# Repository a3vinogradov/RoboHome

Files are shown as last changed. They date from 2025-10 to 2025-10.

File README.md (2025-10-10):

# RoboHome

**Децентрализованная экосистема умного дома**

> *Умный дом, который не тупеет без интернета*

## О проекте

Автономная система, где каждое устройство работает независимо, но может объединяться в единое пространство через протокол RoboHomeLinq.

## 📁 Документация

- [Концепция](Docs/concept.md) - философия и архитектура
- [План разработки](Docs/roadmap.md) - текущий прогресс 
- [История изменений](Docs/concept_changelog.md) - эволюция проекта

## 📜 Лицензия

MIT License

**Автор:** a3v

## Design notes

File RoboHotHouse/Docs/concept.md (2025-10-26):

# **Концепт-документ: RoboHotHouse – Автономная система умной теплицы**

**Версия:** 0.1 

---

## **1. Видение продукта**
**RoboHotHouse** – автономная система для подогрева воздуха в теплице, обеспечивающая безопасную зимовку комнатных растений на балконе.

> *Ключевой принцип: «Не дать цветку замерзнуть!»*

---

## **2. Ключевые характеристики**

| Параметр | Значение/Примечание |
| --- | --- |
| **Измеряемые величины** | Температура, влажность (ANT20), давление (BMP280), освещенность (опционально) |
| **Порог обогрева** | +12°C (активация подогрева) |
| **Связь** | Wi-Fi 2.4 ГГц (внешняя антенна - опционально) |
| **Дисплей** | TFT 1.28" GC9A01 (240x240) |
| **Управление** | Тактовая кнопка (переключение экранов/сброс настроек) |
| **Питание** | ~220В → 5V/3.3V для электроники + 12V для обогревателя |

---

## **3. Аппаратная часть**

### **3.1. Основные компоненты**
- **Микроконтроллер:** ESP32
- **Датчики:** ANT20 (I2C), BMP280 (I2C), LDR (A0 - опционально)
- **Дисплей:** 1.28" TFT GC9A01 (SPI)
- **Управление:** Тактовая кнопка (GPIO16)
- **Обогреватель:** Коврик 5W или резисторы 10W

### **3.2. Безопасность**
- **Механический выключатель** на корпусе
- **Автомат 2А + УЗО** в цепи 220В
- **Закрытый корпус** перед подключением к сети

---

## **4. Программное обеспечение**

### **4.1. Основные функции**
- Непрерывный мониторинг датчиков (30 сек интервал)
- Автоматический обогрев при T < +12°C
- Кольцевой буфер данных (24+ часов истории)
- REST API (`/status` - текущее состояние)
- Интеграция с RoboHome

### **4.2. Логика управления**
- Включение подогрева при снижении температуры ниже 12*С
- Выключение подогрева при повышении температуры до 14*С

### **5. Особенности конструкции**
**Колпак:** Обрезанная бутылка 5л. 
**Корпус:** Основание PLA, крепления PETG
**Антенна:** Возможность подключения внешней для улучшения сигнала

**Лицензия:** MIT
**Автор:** a3v1
**Репозиторий:** gitverse.ru/a3v1/RoboHome

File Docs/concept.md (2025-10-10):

# **Концепт-документ: RoboHome – Автономная экосистема умного дома**  
**Версия:** 0.2  

---

## **1. Видение проекта**  
**RoboHome** – это децентрализованная система умного дома, где каждое устройство автономно, но способно интегрироваться в единую экосистему. 
Ключевая философия:  
> *«Умный дом должен оставаться умным даже без интернета и центрального сервера»*.

---

## **2. Ключевые принципы**  

| Принцип | Реализация в RoboHome |
|---|---|
| **Автономность** | Устройства выполняют основные функции без связи с сервером (например, полив по алгоритму). |
| **Децентрализация** | Нет единой точки отказа. RoboCore выполняет только координационные функции |
| **Локальность** | Приоритет JSON/HTTP в локальной сети. Облако – опционально. |
| **Безопасность** | Многоуровневая валидация всех команд и операций |
| **Масштабируемость**  | Модульная архитектура для легкого добавления новых устройств |

---

## **3. Компоненты системы**  

### **3.1. RoboCore**  
**Роль:** Координатор системы.  
**Функции:**  
- Сбор и агрегация данных от устройств
- Визуализация через веб-интерфейс
- Отправка макрокоманд устройствам 

**Технологии:**  
- ToDo: заполнить  

---

### **3.2. RoboClime**
**Роль:** Комнатная метеостанция  
**Функции:**  
- Замер температуры, влажности, давления, освещенности.  
- Кеширование данных при потере связи.  
- Логирование всех операций

**Железо:**  
- Микроконтроллер: ESP8266-07
- Датчики: CNT-20, BMP-280, LDR

---

### **3.3. RoboHotHouse**
**Роль:** Теплица для зимовки комнатных растений  
**Функции:**  
- Замер температуры, влажности, давления, освещенности.  
- Подогрев при температурах ниже +12.
- Кеширование данных при потере связи.  
- Логирование всех операций

**Железо:**  
- Микроконтроллер: ESP8266-07
- Датчики: CNT-20, BMP-280, LDR
- Нагреватель: Теплый коврик

---

### **3.4. RoboPlant**  
**Роль:** Интеллектуальная система полива.  
**Функции:**  
- Автоматический полив по показаниям датчиков
- REST API для управления
- Контроль уровня воды и обнаружение протечек
- Логирование всех операций

**Железо:**  
- Микроконтроллер: ESP8266-07
- Датчики: влажности почвы, уровня воды
- Исполнительные устройства: насос

---

### **3.5. RoboWind**  
**Роль:** Уличная метеостанция
**Функции:**  
- Замер температуры, влажности, давления.  
- Синхронизация с «Народным мониторингом».  
- Кеширование данных при потере связи.  

**Железо:**  
- ESP8266 + датчики.  

---

## **4. Взаимодействие устройств**  
```mermaid
flowchart LR
    B[RoboCore] ->> |Запрос данных по дате (HTTP)| A[RoboWind]
    A[RoboWind] ->> |Отправка метеоданных за период| B[RoboCore]
    B ->>|Запрос истории состояний по дате (HTTP)| C[RoboPlant]
    C -->|JSON: plant/status| B
```

---

## **5. Техническая реализация**  

### **5.1. Протоколы**  
- **JSON** – основной канал связи (топики: `robohome/[device]/[data]`).  
- **HTTP REST** – для управления (например, ручной запуск полива).  
- **Резервный канал** – Telegram-бот через SIM-модуль (опционально).  

---

## **6. Лицензия и контакты**  
- **Лицензия:** MIT – свободное использование и модификация.  
- **Автор:** a3v  

---

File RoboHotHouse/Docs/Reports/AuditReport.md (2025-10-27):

**Отчет по аудиту компонентов управления нагрузкой ~220В**  
**Проект:** RoboHotHouse  
**Дата проведения аудита:** текущая  
**Цель:** Оценка пригодности имеющихся компонентов для коммутации нагрузки ~220В в системе обогрева.  

---

### **1. Реле механические**  
#### **Наименования:**  
1. **SONGLE SRD-05VDC-SL-C**  
   - **Напряжение катушки:** 5 В  
   - **Коммутируемое напряжение:** ~250 В  
   - **Максимальный ток:** 10 А  
   - **Примечание:** Требуется пропайка разъемов.  

2. **TONGLING JQC-3FF-S-Z**  
   - **Напряжение катушки:** 5 В  
   - **Коммутируемое напряжение:** ~250 В  
   - **Максимальный ток:** 10 А  
   - **Примечание:** Готов к использованию.  

#### **Вывод по механическим реле:**  
- Оба реле подходят для управления нагрузкой ~220В.  
- Ток коммутации (10 А) значительно превышает требуемый для обогревательного коврика (5 Вт ≈ 0.023 А).  
- **Риски:** Наличие механических контактов, возможное искрение при коммутации индуктивной нагрузки.  

---

### **2. Реле твердотельные**  
#### **Наименования:**  
1. **G3MB-202P**  
   - **Напряжение управления:** 5 В  
   - **Коммутируемое напряжение:** 240 В (переменный ток)  
   - **Максимальный ток:** 2 А  
   - **Примечание:** Бесшумная работа, отсутствие механического износа.  

#### **Вывод по твердотельным реле:**  
- Реле **G3MB-202P** полностью удовлетворяет требованиям проекта.  
- Ток коммутации (2 А) избыточен для нагрузки (0.023–0.045 А).  
- **Преимущества:** Отсутствие дребезга контактов, долговечность, совместимость с цифровыми сигналами ESP32.  

---

### **3. Сравнительный анализ**  
| Параметр | Механическое реле | Твердотельное реле |  
|---|---|---|
| **Ток коммутации** | 10 А | 2 А |  
| **Напряжение изоляции** | ~250 В | ~240 В |  
| **Долговечность** | ~100 000 циклов | ~10 000 000 циклов  |  
| **Уровень шума** | Щелчки при работе | Бесшумная работа |  
| **Подключение** | Требует пропайки  | Готово к использованию |  

---

### **4. Рекомендации**  
1. **Твердотельное реле G3MB-202P** является предпочтительным вариантом для проекта благодаря:  
   - Высокой надежности и долговечности.  
   - Бесшумной работе.  
   - Простоте интеграции с ESP32.  
2. **Механические реле** могут быть использованы как резервный вариант, но требуют дополнительной обвязки (например, защитного диода для катушки).  

---

**Заключение:**  
Компоненты, имеющиеся в наличии, полностью пригодны для управления нагрузкой ~220В в рамках проекта RoboHotHouse. Наибольшую эффективность и безопасность обеспечит использование твердотельного реле **G3MB-202P**.  

*Документ подготовлен в рамках Этапа 1 (НИОКР) проекта RoboHotHouse.*

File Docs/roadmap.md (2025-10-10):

## **RoboHome Development Roadmap**  
**Без жесткой привязки к срокам**  
*"Поэтапная разработка с фокусом на архитектуре и интеграции"*  

### 🎯 RoboHome: Единая карта готовности

| Компонент | Концепция | Функциональность | Сетевое подключение | Конфигурируемость | Протокол RoboHomeLinq |
|---|---|---|---|---|---|
| **RoboCore** | ✅ | 🟡 | ✅ | ❌ | ❌ |
| **RoboPlant#1** | ✅ | ✅ | ✅ | ✅ | ❌ |
| **RoboPlant#2** | ✅ | ✅ | ✅ | ✅ | ❌ |
| **RoboWind** | ✅ | ✅ | ✅ | ✅ | ❌ |
| **RoboClime** | ✅ | ✅ | ❌ | ❌ | ❌ |
| **RoboHotHouse** | 🟡 | ❌ | ❌ | ❌ | ❌ |

---

### **Детализация критериев по компонентам**

#### **RoboCore**
- **Концепция**: ✅
  - [x] Проект инициализирован
  - [x] Concept-документ готов
- **Функциональность**: 🟡
  - [~] Веб-интерфейс для мониторинга
  - [x] База данных для хранения показаний
  - **Эмуляторы устройств для тестирования:**
    - [~] Эмулятор RoboBase (абстрактное тестовое устройство)
    - [ ] Эмулятор RoboPlant
    - [ ] Эмулятор RoboWind
    - [ ] Эмулятор RoboClime
    - [ ] Эмулятор RoboHotHouse
- **Сетевое подключение**: ✅
  - [x] Доступен в локальной сети
- **Конфигурируемость**: ❌
  - [ ] Базовая настройка интерфейса
  - [ ] Регистрация нового устройства
- **Протокол RoboHomeLinq**: ❌
  - [ ] Запрос текущего состояния
  - [ ] Запрос истории 
  - [ ] Отправка макрокоманд

#### **RoboClime**
- **Концепция**: ✅
  - [x] Проект инициализирован
  - [x] Concept-документ готов
- **Функциональность**: ✅
  - [x] Замер температуры, влажности, давления, освещенности
  - [x] Органы управления
  - [x] Логирование данных
- **Сетевое подключение**: ❌
  - [ ] Wi-Fi подключение
  - [ ] Локальный HTTP сервер
- **Конфигурируемость**: ❌
  - [ ] Админка в веб-интерфейсе
- **Протокол RoboHomeLinq**: ❌
  - [ ] Предоставление текущего состояния
  - [ ] Предоставление истории показаний
  - [ ] Прием макрокоманд 

#### **RoboHotHouse**
- **Концепция**: 🟡
  - [~] Проект инициализирован
  - [ ] Concept-документ готов
- **Функциональность**: ❌
  - [ ] Замер температуры, влажности, освещенности
  - [ ] Автоматический подогрев при +12°C
  - [ ] Логирование операций и показаний
- **Сетевое подключение**: ❌
  - [ ] Wi-Fi подключение
  - [ ] Локальный HTTP сервер
- **Конфигурируемость**: ❌
  - [ ] Админка в веб-интерфейсе
- **Протокол RoboHomeLinq**: ❌
  - [ ] Предоставление текущего состояния
  - [ ] Предоставление истории показаний
  - [ ] Прием макрокоманд 

#### **RoboPlant**
- **Концепция**: ✅
  - [x] Проект инициализирован
  - [x] Concept-документ готов
- **Функциональность**: ✅
  - [x] Автоматический полив по датчикам влажности почвы
  - [x] Контроль уровня воды в резервуаре
  - [x] Обнаружение протечек
  - [x] Логирование операций
  - [x] Web-интерфейс
- **Сетевое подключение**: ✅
  - [x] Wi-Fi подключение
  - [x] Локальный HTTP сервер
- **Конфигурируемость**: ✅
  - [x] Админка в веб-интерфейсе
- **Протокол RoboHomeLinq**: ❌
  - [ ] Предоставление текущего состояния
  - [ ] Предоставление истории показаний
  - [ ] Прием макрокоманд 

#### **RoboWind**
- **Концепция**: ✅
  - [x] Проект инициализирован
  - [x] Concept-документ готов
- **Функциональность**: ✅
  - [x] Замер температуры, влажности, давления
  - [x] Отправка данных в narodmon.ru
  - [x] Web-интерфейс
- **Сетевое подключение**: ✅
  - [x] Wi-Fi подключение
  - [x] Локальный HTTP сервер
- **Конфигурируемость**: ✅
  - [x] Админка в веб-интерфейсе
- **Протокол RoboHomeLinq**: ❌
  - [ ] Предоставление текущего состояния
  - [ ] Предоставление истории показаний
  - [ ] Прием макрокоманд 

---

### **Ключевые вехи системы**

**Ближайшие цели:**
- [ ] RoboHotHouse: Концепт и реализация устройства
- [ ] RoboCore: Концепт протокола RoboHomeLinq
- [ ] RoboClime: Реализация сетевого подключения

**Целевое состояние:**
- [ ] Все устройства поддерживают протокол RoboHomeLinq
- [ ] RoboCore полностью управляет экосистемой

**Легенда:**
- ✅ - Выполнено
- 🟡 - В процессе
- ❌ - Не готово
- [x] - Задача выполнена
- [~] - Задача в процессе
- [ ] - Задача не начата

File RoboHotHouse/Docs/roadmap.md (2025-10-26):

# **RoadMap проекта RoboHotHouse**
**Версия:** 0.1

---

## **Этап 1. НИОКР**
**Срок:** 28-10-2025 - 11-11-2025
**Цель:** Снижение степени новизны проекта и связанных с этим рисков.

**Задачи:**
1. Исследование способов управления переменной нагрузкой
2. Тестирование доступных способов управления переменной нагрузкой
   - Реле механическое
   - Реле твердотельное
3. Аудит компонентов управления нагрузкой ~220В из наличия
4. Исследование нагревательных возможностей коврика
5. Исследование нагревательных возможностей металло-керамических резисторов
6. Прошивка ESP32 в среде VSCode + PIO
7. Подключение датчиков и дисплея к ESP32
8. Схема управления ~220В с раздельным питанием и гальванической развязкой
9. УЗО
   - Принцип действия, характеристики
   - Выбор УЗО
   - Покупка УЗО
   - Установка УЗО

**Результат:**
- [ ] Отчет по способам управления нагрузкой ~220В
- [ ] Лабораторная работа по управлению нагрузкой ~220В и отчет по ней
- [ ] Отчет по аудиту компонентов управления нагрузкой ~220В
- [ ] Лабораторная работа по исследованию нагревательных возможностей коврика и резисторов. Отчет
- Лабораторные работы по подключению модулей к ESP32
  - [ ] Блинкер
  - [ ] AHT20
  - [ ] BMP280
  - [ ] Дисплей
- [ ] Схема управления нагрузкой ~220В с помощью контроллера
- [ ] Лабораторная работа по управлению нагрузкой ~220В с помощью контроллера
- [ ] Выбор УЗО и автомата. Расчет. Отчет
- [v] Установка защиты (УЗО и автомат) на балконе

##**Этап 2. Высоковольтная часть**
**Срок:** Дни [уточнить по результатам Этапа 1] 
**Цель:** 
- Сделать розетку 220В, которая управлялась бы сигналом 3.3В. 
- Сделать DC-DC преобразователь для обеспечения питания esp32

**Задачи:**
1. Схема электрическая 
2. Определение управляющего интерфейса (с гальванической развязкой)
3. Разводка PCB
4. Плата (ЛУТ)
5. Пайка компонентов 
6. Компоновка
7. 3d модель корпуса
8. Печать корпуса
9. Сборка узла высоковольтной части

**Результат:** 

[ ] Закрытая коробка с
- проводом и вилкой ~220В
- розеткой для включения коврика (не хочу на этом этапе резать провода)
- разъемом JST-npin для выдачи стабилизированных 5В для контроллера и линий управления выключателями (Релейный модуль G3MB-202P предположительно) 

##**Этап 3. Прототип**

**Срок:** *уточнить по результатам Этапа 2*

**Цель:** 
- создание полнофункционального стенда на макетке.

**Задачи:**
1. Сборка стенда на макетке (esp32, aht-20, bmp-280, tft 1.28)
2. Прошивка, реализующая
    - логику управления нагрузкой
    - вывод показателей на дисплей
    - управление дисплеем кнопкой
3. Выходные каскады управления нагрузкой с транзисторами и оптопарами.
4. Подключение к высоковольтному узлу и реальное управление нагрузкой. 
5. Выбор, реализация и настройка алгоритма поддержания заданной температуры. 
6. Проверка на утечку тока и перегрев высоковольтной части.

**Результат:**

- [ ] Стенд на макетке: esp32 и управление нагрузкой по наперед заданному алгоритму
- [ ] Отчет: Проверка на утечку тока и перегрев высоковольтной части.

##**Этап 4. Изделие**

**Срок:**  *уточнить по результатам Этапа 3*

**Цель:** 
- Создать работающее устройство 

**Задачи:**
1. Схема электрическая 
2. Разводка PCB
3. Изготовление платы (ЛУТ)
4. Пайка компонентов (контроллер съемный)
3. Модель корпуса
4. Печать корпуса
5. Сборка изделия
6. Отладка и настройка

**Результат:** 
- [ ] Управление нагрузкой по наперед заданному алгоритму
- [ ] Эстетичное, безопасное устройство.

##**Этап 5. Поддержка RoboHomeLinq**

**Срок:** Не определен. 

**Цель:** 
- Добавление к устройству веб интерфейса и поддержки протокола RoboHomeLinq

**Задачи:**
1. Веб-интерфейс
   - стартовая страница с текущими показаниями
   - настройки 
   - about
2. Страница лога и сам лог
3. Интеграция в RoboHome
   - поддержка протокола RoboHomeLinq
   - добавление адаптеров для RoboHotHouse в RoboCore

**Результат:** 
- RoboHotHouse отображается в интерфейсе RoboCore
- RoboHotHouse выполняет команды, поступившие из интерфейса RoboCore

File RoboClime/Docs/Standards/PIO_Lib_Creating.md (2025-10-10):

# Руководство по созданию библиотек в PlatformIO

## 🎯 **Основные принципы**

### 1. **Структура библиотеки**
```
MyLibrary/
├── library.json          # Обязательно!
├── MyLibrary.h           # Главный заголовок
├── src/                  # Исходные файлы
│   ├── Class1.h
│   ├── Class2.cpp
│   └── ...
└── examples/             # Примеры использования
    └── BasicExample/
        └── BasicExample.ino
```

### 2. **Критически важные моменты**
- **library.json** - должен быть в корне библиотеки
- **MyLibrary.h** - главный заголовок должен быть в корне
- **Платформа** - указывайте поддерживаемые платформы

## 📝 **Пошаговое создание библиотеки**

### Шаг 1: Создаем структуру папок
```bash
# В папке lib/ вашего проекта
mkdir MyLibrary
cd MyLibrary
mkdir src examples
```

### Шаг 2: Создаем library.json
```json
{
    "name": "MyLibrary",
    "version": "1.0.0",
    "description": "Описание вашей библиотеки",
    "keywords": "keyword1, keyword2",
    "authors": [
        {
            "name": "Ваше имя",
            "email": "email@example.com"
        }
    ],
    "frameworks": "arduino",
    "platforms": "espressif8266, espressif32",
    "build": {
        "includeDir": ".",
        "srcDir": "src"
    }
}
```

**Ключевые параметры:**
- `"includeDir": "."` - указывает, где искать заголовочные файлы
- `"srcDir": "src"` - указывает, где исходные файлы

### Шаг 3: Создаем главный заголовок (MyLibrary.h)
```cpp
#pragma once

// Главный заголовок библиотеки
#include "src/MyClass.h"
#include "src/MyConfig.h"

namespace MyLibrary {
    // Объявления или using-директивы
}
```

### Шаг 4: Создаем исходные файлы в src/
**src/MyClass.h:**
```cpp
#pragma once
#include <Arduino.h>

namespace MyLibrary {
    class MyClass {
    public:
        void begin();
        void update();
    private:
        // поля класса
    };
}
```

**src/MyClass.cpp:**
```cpp
#include "MyClass.h"

namespace MyLibrary {
    void MyClass::begin() {
        // инициализация
    }
    
    void MyClass::update() {
        // основная логика
    }
}
```

### Шаг 5: Создаем пример использования
**examples/BasicExample/BasicExample.ino:**
```cpp
#include <MyLibrary.h>

MyLibrary::MyClass myObject;

void setup() {
    Serial.begin(115200);
    myObject.begin();
}

void loop() {
    myObject.update();
    delay(100);
}
```

## ⚙️ **Конфигурация platformio.ini**
```ini
[env:nodemcuv2]
platform = espressif8266
board = nodemcuv2
framework = arduino

; Библиотека автоматически подхватится из lib/
; Явное указание не требуется, но можно добавить:
lib_deps = 
    MyLibrary
```

## 🔧 **Работа с зависимостями**

### Зависимость от другой библиотеки
**library.json:**
```json
{
    "name": "MyLibrary",
    "version": "1.0.0",
    "dependencies": {
        "SomeOtherLibrary": "*"
    },
    "build": {
        "includeDir": ".",
        "srcDir": "src"
    }
}
```

### Вложенные зависимости
Если ваша библиотека зависит от другой вашей же библиотеки:
```json
{
    "dependencies": {
        "EventLib": "*",
        "ButtonLib": "*"
    }
}
```

## 🐛 **Диагностика проблем**

### 1. Библиотека не находится
**Симптом:** `fatal error: MyLibrary.h: No such file or directory`

**Решение:**
- Проверьте наличие `library.json`
- Убедитесь, что `MyLibrary.h` в корне библиотеки
- Добавьте в `platformio.ini`:
  ```ini
  lib_extra_dirs = lib/MyLibrary
  build_flags = -Ilib/MyLibrary
  ```

### 2. Файлы внутри библиотеки не находятся
**Симптом:** Ошибки компиляции файлов внутри src/

**Решение:**
- В `MyLibrary.h` используйте правильные пути:
  ```cpp
  #include "src/MyClass.h"    // если файлы в src/
  #include "MyClass.h"        // если файлы в корне
  ```

### 3. Проверка видимости библиотеки
```bash
# Убедитесь, что PlatformIO видит библиотеку
pio lib list

# Принудительно обновить кэш библиотек
pio pkg update
```

## 🚀 **Продвинутые настройки**

### Многофайловая библиотека
```
MyLibrary/
├── library.json
├── MyLibrary.h
├── src/
│   ├── Core/
│   │   ├── Core.h
│   │   └── Core.cpp
│   ├── Network/
│   │   ├── Network.h
│   │   └── Network.cpp
│   └── Sensors/
│       ├── Sensor.h
│       └── Sensor.cpp
└── examples/
    ├── BasicExample/
    └── AdvancedExample/
```

**MyLibrary.h:**
```cpp
#pragma once

// Подключаем все компоненты
#include "src/Core/Core.h"
#include "src/Network/Network.h"
#include "src/Sensors/Sensor.h"

namespace MyLibrary {
    // Объединяем все пространства имен
    using namespace Core;
    using namespace Network;
    using namespace Sensors;
}
```

## 💡 **Лучшие практики**

1. **Именование** - используйте осмысленные имена, избегайте пробелов
2. **Версионирование** - следуйте семантическому версионированию (1.0.0, 1.0.1, etc.)
3. **Документация** - добавляйте комментарии и примеры
4. **Тестирование** - создавайте примеры в папке examples/
5. **Совместимость** - явно указывайте поддерживаемые платформы

## 📋 **Чеклист создания библиотеки**

- [ ] Создана папка библиотеки в `lib/`
- [ ] Добавлен `library.json` с правильными путями
- [ ] Создан главный заголовок `MyLibrary.h`
- [ ] Исходные файлы размещены в `src/`
- [ ] Добавлены примеры в `examples/`
- [ ] Протестирована компиляция
- [ ] Указаны зависимости (если есть)

Теперь вы можете создавать хорошо структурированные библиотеки в PlatformIO! 🎉

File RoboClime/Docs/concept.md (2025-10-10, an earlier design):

# **Концепт-документ: RoboClime – Автономный модуль мониторинга микроклимата**

**Версия:** 0.3 

---

## **1. Видение продукта**

**RoboClime** – это компактный модуль для точного мониторинга параметров атмосферы (температура, влажность, давление). Устройство является частью экосистемы RoboHome и фокусируется на надежности данных за счет аппаратной изоляции датчиков.

> *Ключевой принцип: «Точные данные здесь и сейчас. Стабильность важнее функций».*

---

## **2. Ключевые характеристики**

| Параметр | Значение/Примечание |
| --- | --- |
| **Измеряемые величины** | Температура, относительная влажность (ANT20), атмосферное давление (BMP280), **освещенность (опционально)**|
| **Связь** | Wi-Fi 2.4 ГГц (внешняя штыревая антенна - **опционально**) |
| **Интерфейсы** | USB Type-C (питание 5V) |
| **Управление** | Тактовая кнопка (основной орган) с возможностью параллельного подключения вибродатчика (опционально, для тестирования в реальных условиях). |
| **Плата** | Односторонняя (ЛУТ) |
| **Корпус** | 3D-печать, **двойные стенки с воздушным зазором** для термоизоляции датчиков |
| **Обновление прошивки**| Внутренний разъем для программатора |

---

## **3. Аппаратная часть**

### **3.1. Ядро системы**
*   **Микроконтроллер:** ESP8266-07 flash 1М
*   **Датчики:**
    *   ANT20 (Temperature & Humidity, I2C)
    *   BMP280 (Barometric Pressure, I2C)
	*   Датчик освещенности (опционально, аналоговый вход A0)
*   **Дисплей** 1.28" TFT GC9A01 (240x240)
*   **Орган управления:** Тактовая кнопка (GPIO16). На плате реализована возможность параллельного подключения вибродатчика для полевых испытаний.
*   **Антенная система:** Возможность подключения внешней антенны (опционально)
*   **Резерв:** Выведенная контактная площадка (GPIO12) для будущих расширений (управление подсветкой, тач-скрин и т.д.)

### **3.2. Конструктивные особенности**
*   **Термоизоляция:** Датчики вынесены в изолированный отсек с двойными стенками
*   **Вентиляция:** Отверстия для вентиляции только в зоне датчиков
*   **Доступ:** Лючок для доступа к разъему программатора

---

## **4. Программное обеспечение**

### **4.1. Прошивка**
*   **Режим работы:** Постоянное питание от USB
*   **Управление дисплеем:** Постоянная работа. Яркость фиксированная (аппаратная).
*   **Взаимодействие:** REST API для предоставления данных (`/status`)

### **4.2. Логика работы**
1. Непрерывный опрос датчиков 
2. Хранение истории показаний в кольцевом буфере
3. Предоставление данных по API

---

## **5. Особенности реализации**
*   **Стратегия внедрения:** Функциональность устройства в ограниченном объеме реализуется и тестируется на макетной плате (Стенд 1, NodeMCU) до этапа изготовления конечного изделия. Это гарантирует готовность системы к мониторингу к началу ночных заморозков, даже если сроки изготовления корпуса и платы будут сдвинуты.
*   **Орган управления:** Тактовая кнопка подключена на GPIO16. Возможность подключения вибродатчика реализована аппаратно для тестирования.
*   **Термоизоляция:** Физическое отделение датчиков от источников тепла
*   **Разъем программатора:** 5-пиновый (GPIO0, RST, TX, RX, GND) для легкого обновления

---

**Лицензия:** MIT  
**Автор:** a3v1  
**Репозиторий:** gitverse.ru/a3v1/RoboHome  

---

**Утверждено к реализации.**  
Начало работ: 25-08-2025  
Плановый срок завершения: 42 дня

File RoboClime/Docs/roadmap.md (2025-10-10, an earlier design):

# **Дорожная карта (Roadmap) проекта RoboClime**
**Версия:** 0.4
**Общий срок:** 46 дней

---

### **Этап 1: НИОКР (Исследования и подготовка)**
**Срок:** Дни 1-7 (28.08 - 03.09)
**Цель:** Подготовить все компоненты и решения для быстрой сборки прототипа.

| Задача | Результат | Статус |
| --- | --- | ---|
| **1.1. Конструктив разъема программатора**  | Выбран тип разъема (скорее всего, 6-пиновый SH1.0). Спроектирована отладочная плата с кнопками FLASH и RST. | ✅ Выполнено с изменениями|
| **1.2. Изготовление шлейфа программатора**  | Готовый шлейф с ключом/полярностью, исключающей неправильное подключение к целевому устройству. | ✅ Выполнено без ключа|
| **1.3. Тест вибродатчика (SW-18020P)** | Подтверждена чувствительность на падение с высоты 1-2 см. Подобран резистор для нужной чувствительности. | ✅ Выполнено | 
| **1.4. Тест дисплея 1.28 TFT** | Вывод пикселя, символа, примитива, картинки | ✅ Выполнено |

*Сроки сдвинуты на 2 дня.*

---

### **Этап 2: Прототип на макетке**
**Срок:** Дни 10-21 (04.09 - 16.09)
**Цель:** Собрать и проверить работоспособность всей схемы и логики.

| Задача  | Результат  | Статус |  
| --- | --- | --- |
| **2.1. Сборка на макетке** | ESP8266, дисплей, датчики (ANT20+BMP280).  | ✅ Выполнено |
| **2.2. Базовая прошивка (Foundation)** | Прошивка, которая выводит данные с всех датчиков в Serial Monitor. Проверка работы I2C.  |✅ Выполнено |
| **2.3. Прошивка**  | Вывод на экран текущей температуры, температурных экстремумов за последние сутки |✅ Выполнено |
| **2.4. Прошивка (Сеть и WEB)** | Поднят простейший WEB-сервер. Страница `192.168.x.x/status` возвращает JSON с данными датчиков.  | Отложено на 4 этап |

---
### **Этап 2.5: Внеочередной НИОКР**
**Срок:** Дни 22-24 (17.09 - 18.09)
**Цель:** Аудит GPIO в проекте с целью подтвердить возможность подключения тактовой кнопки и/или вибродатчика.
| Задача  | Результат  | Статус |  
| --- | --- | --- |
| **2.5.1 Карта GPIO**| Составить список существующих GPIO. Составить список уже занятых GPIO. Определить количество свободных GPIO  | ✅ Выполнено |
| **2.5.2 Тест кнопки и вибродатчика**| Проверить возможность параллельного включения тактовой кнопки и вибродатчика. Подтвердить возможность использования такой схемы для сброса настроек wifi| ✅ Выполнено |
| **2.5.3 Тест датчика освещенности**| Проверить возможность использования датчика освещенности.| ✅ Выполнено |

### **Этап 3: Изделие (Корпус, плата, сборка)**
**Срок:** Дни 25-46 (19.09 - 10.10) 
**Цель:** Создать готовое к использованию устройство.
**Итог:** Устройство собрано, прошито и запущено в эксплуатацию. Расхождение температур со стендом #1 менее 0.3°C - в пределах допустимой погрешности.

| Задача  | Результат  | Статус | 
| --- | --- | --- |
| **3.1. Моделирование корпуса (Fusion 360)** | Готовая 3D-модель корпуса с двойными стенками, посадочными местами под плату и разъем программатора.  | ✅ Выполнено |
| **3.2. Печать и доводка корпуса** | Напечатанный и доведенный (подшлифованный) корпус. Проверка совместимости всех компонентов. | ✅ Выполнено |
| **3.3. Схема и разводка платы (ЛУТ)** | Готовая к переносу на текстолит односторонняя схема. Все компоненты помещаются в корпус. | ✅ Выполнено |
| **3.4. Изготовление и пайка платы** | Готовая паяная плата, установленная в корпус. | ✅ Выполнено |
| **3.5. Изготовление и пайка платы программатора** | Готовая паяная плата программатора | ✅ Выполнено |
| **3.6. Финальная прошивка ("Продакшн")** | **Готовое изделие.** Вывод на дисплей текущей температуры и суточных экстремумов. | ✅ Выполнено (Рефакторинг отложен на 4 этап) |

---
**Примечание:** Этап 3 успешно завершен 10.10.2025. Все работы по рефакторингу и улучшениям переносятся на Этапы 4 и 5. Сроки по этапам 4 и 5 будут уточнены отдельно.

---
### **Этап 4: Доработка прошивки (После 37 дней)**
*   **4.0. Техдолг: глубокий рефакторинг прошивки. Аудит компонентов.
*   **4.1. Страница Index** Вывод текущих показаний температуры и суточных экстремумов.
*   **4.2. Страница About** Вывод информации о проекте.
*   **4.3. Страница Settings** Настройки wifi, периода опроса, времени сброса экстремумов и т.п.
*   **4.4. Страница с логом показаний:** Вывод истории измерений за последние N часов.
*   **4.5. Реализация REST API:** Полноценное API для интеграции с RoboHome (отправка данных, управление).

---
### **Этап 5: Улучшения (После 37 дней)**
*   **5.1. Анимация на дисплее:** Плавные графики или визуализация данных прямо на дисплее.
*   **5.2. Диаграммы в WEB-интерфейсе:** Построение графиков температуры/давления прямо в браузере.
*   **5.3. Управление** Сенсор переключает страницы. Определить состав данных на страницах и логику переключения
*   **5.4. Реализация функционала датчика освещенности** периодический опрос датчика, сохранение истории, графики, совмещенные с температурой.

---

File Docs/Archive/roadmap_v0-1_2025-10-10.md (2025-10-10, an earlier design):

### **RoboHome Development Roadmap**  
**Без жесткой привязки к срокам**  
*"Поэтапная разработка с фокусом на архитектуре и интеграции"*  

---

### **🔹 Этап 1: Архитектура ядра (RoboCore)**  
**Цель:** Проектирование и базовая реализация центрального модуля управления.  

| Компонент | Задачи | Критерии завершения |
|---|---|---|
| **Ядро системы** | - Определение API-интерфейсов<br>- Реализация JSON-протокола | - Готовы спецификации API<br>- Рабочий HTTP-сервер |
| **База данных** | - Выбор СУБД (PostgreSQL)<br>- Схема хранения данных | - Сохранение/чтение тестовых данных |
| **UI** | - Веб-интерфейс (админ-панель + клиентская часть) | - Готова админка и фронтенд <br>- Интерфейс поддерживает основные сценарии управления |

---

### **🔹 Этап 2: Эмулятор метеостанции**  
**Цель:** Создание программного эмулятора RoboWind для тестирования.  

| Компонент | Задачи | Критерии завершения |
|---|---|---|
| **Эмулятор** | - Генерация тестовых данных (T/H/P)<br>- REST API для управления | - Имитация реального устройства |
| **Интеграция** | - Подключение к RoboCore<br>- Тестирование передачи данных | - Корректное отображение в веб-интерфейсе  |

---

### **🔹 Этап 3: Эмулятор автополивалки**  
**Цель:** Виртуальная модель RoboPlant для отладки логики.  

| Компонент | Задачи | Критерии завершения |
|---|---|---|
| **Эмулятор** | - Моделирование полива<br>- Имитация датчиков влажности | - Реализация всех API-эндпоинтов |
| **Интеграция** | - Тестирование с RoboCore<br>- Проверка реакций на команды | - Автоматический полив по данным от RoboCore |

---

### **🔹 Этап 4: Создание автополивалки (v3)**  
**Цель:** Разработка третьего экземпляра автополивалки.  

| Компонент | Задачи | Критерии завершения |
|---|---|---|
| **Аппаратная часть** | - Проектирование и создание автономного устройства <br>- добавление сервиса RoboPlant | - Устойчивая работа в реальных условиях |
| **Прошивка** | - Разработка и оптимизация прошивки | - Соответствие спецификациям API |
| **Интеграция** | - Подключение к RoboCore<br>- Настройка синхронизации | - Передача данных без потерь |

---

### **🔹 Этап 5: Доработка метеостанции**  
**Цель:** Апгрейд RoboWind и интеграция в систему.  

| Компонент | Задачи | Критерии завершения |
|---|---|---|
| **Прошивка** | - Обновление Веб-интерфейса и алгоритмов <br>- Совместимость с новым API | - Соответствие спецификациям API |
| **Интеграция** | - Подключение к RoboCore<br>- Настройка синхронизации | - Передача данных без потерь |

---

### **🔹 Этап 6-7: Доработка поливалок (v1-v2)**  
**Цель:** Улучшение предыдущих версий RoboPlant.  
*v1 и v2 — legacy-устройства, требующие доработки под новый API*

| Компонент | Задачи | Критерии завершения |
|---|---|---|
| **Аппаратная часть** | - Добавление зуммера<br>- Добавление датчика протечки <br>- Апгрейд датчика уровня жидкости в резервуаре | - Устойчивая работа в реальных условиях |
| **Прошивка** | - Обновление Веб-интерфейса и алгоритмов <br>- Совместимость с новым API | - Соответствие спецификациям API |
| **Интеграция** | - Подключение к RoboCore<br>- Настройка синхронизации | - Передача данных без потерь |

---

### **🔹 Этап 8: Финальная интеграция**  
**Цель:** Объединение всех компонентов в единую систему.  

| Задача | Подзадачи | Критерии завершения |
|---|---|---|
| **Тестирование** | - Проверка устойчивости сети<br>- Stress-тесты API | 48 часов бесперебойной работы |
| **Оптимизация** | - Настройка энергопотребления<br>- Сжатие передаваемых данных | Снижение трафика на 30% |
| **Документация** | - Руководство пользователя<br>- API-документация (Swagger) | Покрытие всех функций |

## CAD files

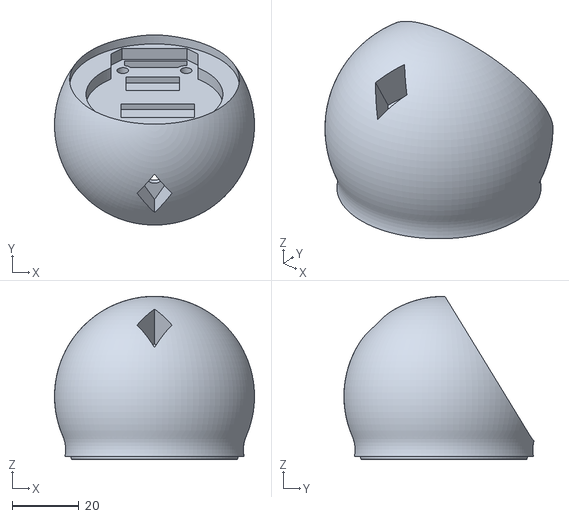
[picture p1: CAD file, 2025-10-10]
RoboClime/3dModels/RC_RoboHead.stl
60.0 x 57.0 x 49.0

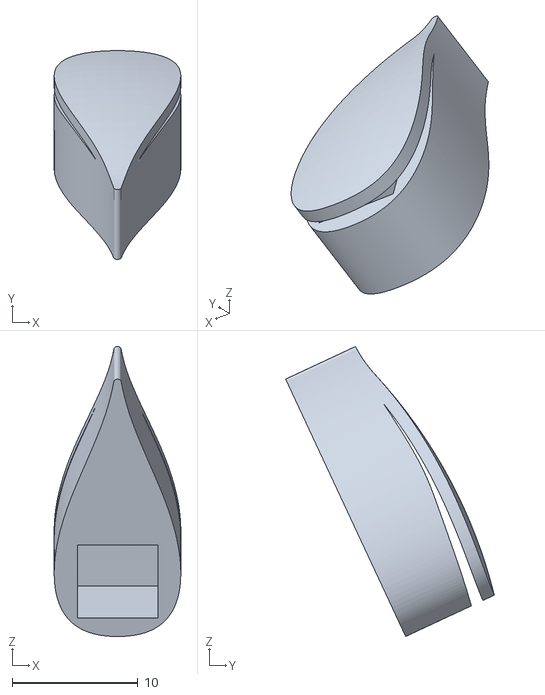
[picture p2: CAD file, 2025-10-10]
RoboClime/3dModels/RC_ButtonSocket.stl
10.1 x 16.6 x 23.1

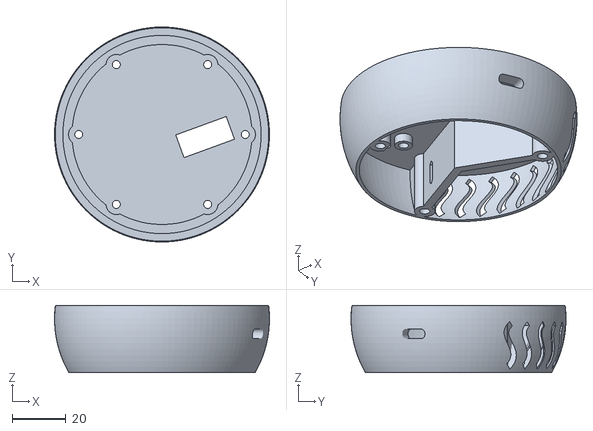
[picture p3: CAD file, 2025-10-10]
RoboClime/3dModels/RC_ButtPlate.stl
80.0 x 80.0 x 25.0

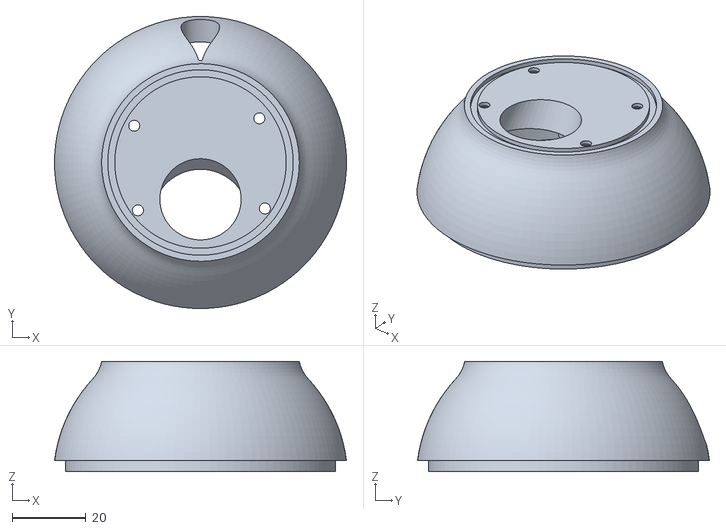
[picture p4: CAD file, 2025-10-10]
RoboClime/3dModels/RC_Thorax.stl
79.4 x 79.4 x 30.0

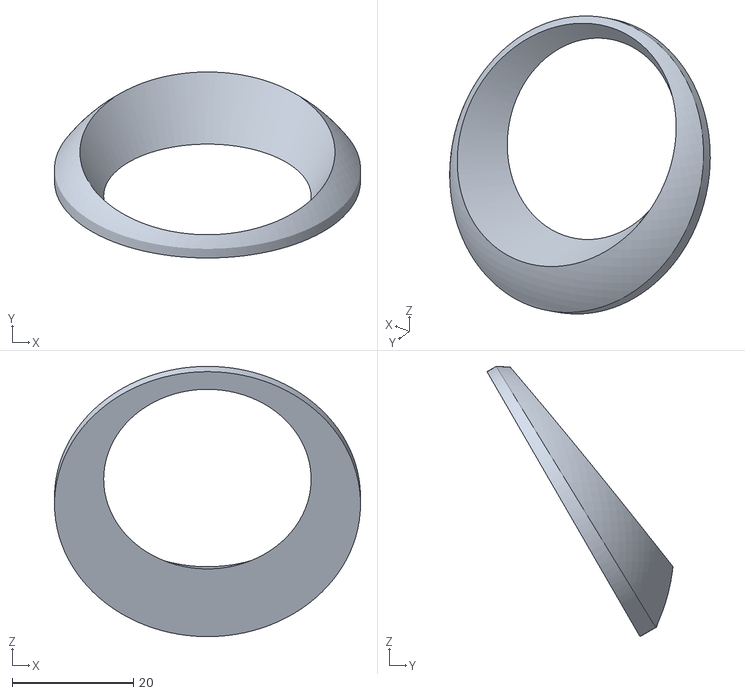
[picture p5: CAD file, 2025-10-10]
RoboClime/3dModels/RC_DisplayBezel.stl
50.5 x 30.7 x 44.6

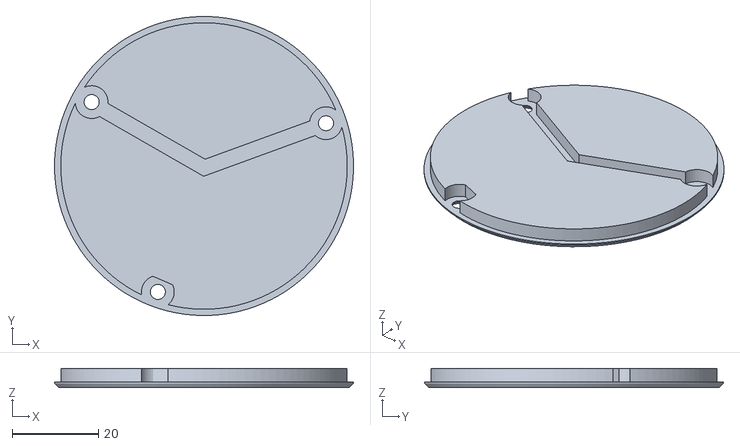
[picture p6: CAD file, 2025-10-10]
RoboClime/3dModels/RC_BasePlate.stl
69.3 x 69.3 x 4.50

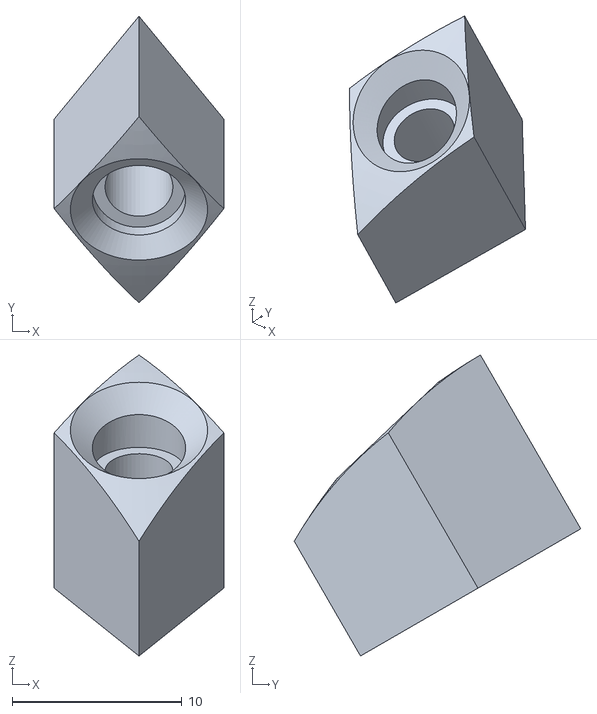
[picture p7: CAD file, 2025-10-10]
RoboClime/3dModels/RC_LDRSocket.stl
10.0 x 16.9 x 17.7

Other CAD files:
RoboClime/3dModels/RoboClimeAssembly.f3d
RoboClime/3dModels/RoboClimeLib.f3d

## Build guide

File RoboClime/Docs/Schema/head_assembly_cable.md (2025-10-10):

### **Кабель подключения "Голова → Грудь"**

#### **Состав жгута (9 проводов):**
- **Дисплей:** 7 проводов
- **LDR:** 2 провода

#### **Разделение на разъёмы:**
- **Разъём 1 (5-pin):** Дисплей — наиболее "толстый" пучок проводов
- **Разъём 2 (4-pin):** Дисплей (оставшиеся провода) + LDR

#### **Цветовая маркировка:**
- **GND:** Синий
- **VCC:** Красный
- **Остальные провода:** Разные цвета для каждого сигнала

#### **Сборка:**
1. Пайка проводов к дисплею
2. LDR подключается через 2-pin коннектор (полярность не важна)
3. Все 9 проводов собираются в единый жгут
4. В конце жгута провода разделяются и обжимаются в два разъёма (5-pin и 4-pin)

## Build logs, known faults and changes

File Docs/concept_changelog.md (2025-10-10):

### **Changelog: Концепт-документ RoboHome**

**Версия 0.2** 
* **Дата:** 10-10-2025
* **Основание:** Расширение экосистемы устройствами для комнатного использования.
* **Добавлено**
  * Новый компонент **RoboClime** - комнатная метеостанция
  * Новый компонент **RoboHotHouse** - интеллектуальная теплица
  * Конкретные модели датчиков для всех устройств:
    * CNT-20 (температура/влажность)
    * BMP-280 (давление) 
    * LDR (освещенность)
  * Исполнительные устройства (теплый коврик для RoboHotHouse)
* **Изменено**
  * Обновление версии документа до 0.2
  * Убраны пометки "(в планировании)" для всех компонентов
  * Детализировано аппаратное обеспечение для всех устройств
  * Добавлен автор проекта (a3v)
  * Улучшена структура документа

---

**Версия 0.1** (Исходная)
* **Дата:** 26-06-2025
* **Основание:** Первичная разработка концепции.
* **Добавлено**
	* Первичная разработка концепции проекта
	* Определение видения и философии проекта
	* Формулировка ключевых принципов системы:
		* Автономность устройств
		* Децентрализованная архитектура  
		* Локальность вычислений
		* Безопасность операций
		* Масштабируемость системы
	* Описание компонентов экосистемы:
		* RoboCore (координатор системы)
		* RoboPlant (интеллектуальная система полива)
		* RoboWind (уличная метеостанция)
	* Схема взаимодействия между устройствами
	* Определение технических протоколов (JSON/HTTP)
	* Лицензия MIT для открытого развития

---

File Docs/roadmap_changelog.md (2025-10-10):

### **Roadmap Changelog: RoboHome Development Roadmap**
**Версия 0.2** 
* **Дата:** 10-10-2025
* **Основание:** Изменение концепта.
* **Убрано:**
  * Жесткая этапность (8 последовательных этапов)
  * Привязка к конкретным техническим решениям (PostgreSQL)
  * Детальные таблицы с подзадачами для каждого этапа
* **Добавлено**
  * Критериальная система (5 универсальных критериев)
  * Единая карта готовности для всех компонентов
  * Гибкий подход без временных обязательств
  * Протокол RoboHomeLinq как ключевой элемент
  * Чекбоксовая система для трекинга прогресса
* **Сохранено**
  * Фокус на архитектуре и интеграции
  * Принцип поэтапной разработки
  * Важные технические детали (в виде критериев)

**Версия 0.1** (Исходная)
* **Дата:** 26-06-2025
* **Основание:** Создание первоначальной дорожной карты развития проекта.
* **Добавлено**
  * Разработка поэтапного плана развития системы RoboHome
  * Определение 8 ключевых этапов разработки:
    * Архитектура ядра (RoboCore)
    * Эмулятор метеостанции (RoboWind)
    * Эмулятор автополивалки (RoboPlant)
    * Создание автополивалки v3
    * Доработка метеостанции
    * Доработка поливалок v1-v2
    * Финальная интеграция
  * Формирование структуры для каждого этапа:
    * Четкие цели и задачи
    * Конкретные критерии завершения
    * Детализация компонентов и подзадач
  * Установка принципов разработки:
    * Без жесткой привязки к срокам
    * Фокус на архитектуре и интеграции
    * Поэтапная реализация с тестированием
  * Определение технологического стека:
    * PostgreSQL для базы данных
    * REST API для взаимодействия
    * Веб-интерфейс для управления

---

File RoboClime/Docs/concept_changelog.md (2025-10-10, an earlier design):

### **Changelog: Концепт-документ RoboClime**

**Версия 0.3** (Актуальная)
*   **Дата:** 18-09-2025
*   **Основание:** Результаты Этапа 2.5 (Аудит GPIO)
*   **Изменения:**
    *   **Общее:** Удалены поля "Статус" и "Кодовое имя" как избыточные для personal use.
    *   **Видение продукта:** Добавлена "освещенность" в список измеряемых величин.
    *   **Ключевые характеристики:**
        *   В измеряемые величины добавлена "освещенность (опционально)".
        *   Раздел "Управление" полностью переработан: указана тактовая кнопка с опциональным вибродатчиком.
    *   **Аппаратная часть:**
        *   Добавлен "Датчик освещенности (опционально, аналоговый вход A0)".
        *   Орган управления изменен на "Тактовая кнопка (GPIO16)" с пояснением о возможности подключения вибродатчика.
        *   Добавлен пункт о резервной контактной площадке (GPIO12).
    *   **Плановый срок:** Обновлен с 35 до 42 дней.
    *   **Утверждение:** Удалена строка "Утверждено к реализации".

**Версия 0.2** 
*   **Статус:** Утвержденная концепция
*   **Дата:** 04-09-2025
*   **Основание:** Результаты ретроспективы Этапа 1 (НИОКР)
*   **Изменения:**
    *   **Управление:** Ключевое изменение. Орган управления изменен с «Сенсор вибрации» на «Интерактивное управление (наклон/встряхивание)». Окончательный выбор сенсора и реализация делегированы на этап схемотехники и будут приняты по остаточному принципу.
    *   **Аппаратная часть:** Добавлен явный пункт «Дисплей 1.28" TFT GC9A01 (240x240)» в раздел «Ядро системы».
    *   **Аппаратная часть:** Уточнена модель микроконтроллера до «ESP8266-07 flash 1М».
    *   **Программное обеспечение:** В логике работы акцент смещен с управления по прерыванию на непрерывный опрос и хранение истории в кольцевом буфере.
    *   **Особенности реализации:** Добавлен новый пункт «Стратегия внедрения», описывающий подход с использованием макетной платы (NodeMCU) как страховочного варианта для своевременного начала мониторинга.
    *   **Особенности реализации:** Описание реализации органа управления обобщено до «Выбранный сенсор... подключается на аппаратное прерывание».
    *   **Особенности реализации:** Уточнена конфигурация разъема программатора до «5-пиновый (GPIO0, RST, TX, RX, GND)».

**Версия 0.1** (Исходная)
*   **Статус:** Утвержденная концепция
*   **Дата:** 29-08-2025
*   **Основание:** Первичная разработка концепции.
*   **Ключевые элементы:**
    *   Определение видения и ключевого принципа.
    *   Выбор компонентов: ESP8266-07S, ANT20, BMP280.
    *   Концепция управления на основе вибродатчика (SW-18020P).
    *   Конструкция с термоизоляцией датчиков.
    *   Определение базовой логики работы и WEB-интерфейса.

---

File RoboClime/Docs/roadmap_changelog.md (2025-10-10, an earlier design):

# Changelog: Дорожная карта (Roadmap) проекта RoboClime

### [Версия 0.5] - 2025-10-10
**Основание:** Фиксация результатов выполнения Этапа 3 (Изделие) и актуализация плана разработки.

**Изменения:**
- **Этап 3 (Изделие):**
  - Все задачи этапа отмечены статусом "✅ Выполнено"
  - Срок выполнения скорректирован с "Дни 25-42" на "Дни 25-46" (19.09 - 10.10)
  - Добавлен итог этапа: устройство собрано и запущено в эксплуатацию
  - Отмечено, что расхождение температур со стендом #1 менее 0.3°C
- **Обновление версии:** Номер версии изменен с 0.4 на 0.5

**Примечание:** Этап 3 успешно завершен. Работы по рефакторингу и улучшениям переносятся на Этапы 4 и 5.

### [Версия 0.4] - 2025-09-18
**Статус:** Актуальная версия
**Основание:** Фиксация результатов выполнения Этапа 2.5 (Внеочередной НИОКР) и актуализация плана разработки.

**Изменения:**
- **Структура документа:** Из заголовка удалено поле "Статус:".
- **Принцип ведения:** Актуальность документа определяется исключительно его версией и датой. Все версии в репозитории считаются утверждёнными к использованию.
- **Этап 2.5 (Внеочередной НИОКР):**
  - Все задачи этапа отмечены статусом "✅ Выполнено":
    - Задача 2.5.1: "Карта GPIO" - завершена, определены свободные пины
    - Задача 2.5.2: "Тест кнопки и вибродатчика" - тестирование завершено, подтверждена возможность параллельного подключения
    - Задача 2.5.3: "Тест датчика освещенности" - добавлена новая задача, тестирование завершено успешно
- **Этап 5 (Улучшения):**
  - Добавлена новая задача 5.4: "Реализация функционала датчика освещенности" - включает периодический опрос датчиков, сохранение истории, построение графиков совмещенных с температурой
- **Обновление версии:** Номер версии изменен с 0.3 на 0.4

**Технические решения, отраженные в изменениях:**
- Подтверждена возможность использования GPIO16 для тактовой кнопки
- Одобрена концепция параллельного подключения вибродатчика
- Добавлена поддержка датчика освещенности на аналоговом входе A0
- Зарезервирован GPIO12 для будущих расширений

---
**Примечания:** 
- Изменения внесены для синхронизации дорожной карты с результатами аппаратного аудита и тестирования компонентов. План готов к реализации Этапа 3.
- Для personal use проекта статус документа ("Черновик", "Утверждено") является избыточным и более не указывается. Факт наличия документа в репозитории означает его актуальность.

### [Версия 0.3] - 2025-09-16
**Статус:** Утверждена
**Основание:** Результаты ретроспективы Этапа 2 (Прототип на макетке). Актуализация плана по итогам выполнения работ и выявления новых требований.

**Изменения:**
- **Общий срок:** Увеличен с 37 до 42 дней. Основание: добавление внеочередного НИОКР и смещение сроков этапа разработки прототипа.
- **Этап 2 (Прототип на макетке):**
  - Добавлена колонка "Статус" с результатами выполнения:
    - Задача 2.1: "✅ Выполнено"
    - Задача 2.2: "✅ Выполнено"
    - Задача 2.3: "✅ Выполнено"
    - Задача 2.4: "⏸️ Отложено до Этапа 4"
  - Добавлена пометка: *"Сроки сдвинуты на 2 дня."*
- **Добавлен новый этап:**
  - **Этап 2.5: Внеочередной НИОКР** (3 дня). Цель: аудит GPIO и проверка возможности совместного подключения кнопки и вибродатчика.
- **Этап 3 (Изделие):**
  - Срок изменен с "Дни 19-35" на "Дни 25-42" в связи с добавлением нового этапа.
  - В задаче 3.6 уточнен ожидаемый результат: "Вывод на дисплей текущей температуры и суточных экстремумов".
- **Этап 4 (Доработка прошивки):**
  - Нумерация задач исправлена (добавлена недостающая задача 4.4).
  - Уточнено содержание: перенесенные с Этапа 2 задачи по веб-интерфейсу детализированы до конкретных страниц (Index, About, Settings).
- **Этап 5 (Улучшения):** Без изменений.

**Примечание:** Изменения внесены для синхронизации дорожной карты с текущим состоянием проекта и принятыми по итогам ретроспективы решениями.

### [Версия 0.2] - 2025-09-03
**Статус:** Утверждена
**Основание:** Актуализация по итогам ретроспективы Этапа 1 (НИОКР) и утверждения Концепт-документа v0.2

**Изменения:**
- **Общий срок:** Увеличен с 35 до 37 дней
- **Этап 1:** Добавлена колонка "Статус" с детализацией выполнения задач:
  - Задача 1.1: "✅ Выполнено с изменениями"
  - Задача 1.2: "✅ Выполнено без ключа"
  - Задача 1.3: "✅ Выполнено"
  - Задача 1.4: "✅ Выполнено"
- **Этап 2:** 
  - Срок изменен с "Дни 8-18" на "Дни 10-19"
  - Задача 2.1: Упрощено описание, удалено упоминание вибродатчика
- **Этап 3:**
  - Срок изменен с "Дни 19-35" на "Дни 20-37"
  - Добавлена задача 3.5: "Изготовление и пайка платы программатора"
  - Перенумерована финальная задача с 3.5 на 3.6
- **Этап 5:** Добавлена задача 5.3: "Управление. Сенсор переключает страницы"

### [Версия 0.1] - 2025-08-25
**Статус:** Утверждена
**Основание:** Первичная разработка дорожной карты

**Ключевые элементы:**
- Общий срок: 35 дней
- Этап 1: НИОКР (7 дней) - исследования и подготовка компонентов
- Этап 2: Прототип на макетке (11 дней) - сборка и базовая прошивка
- Этап 3: Изделие (17 дней) - корпус, плата, финальная сборка
- Этапы 4-5: Доработка и улучшения (после основного срока)
- Включены задачи по вибродатчику и управлению подсветкой

---
**Примечание:** Архивные версии документов хранятся в папке `Docs/Archive/`

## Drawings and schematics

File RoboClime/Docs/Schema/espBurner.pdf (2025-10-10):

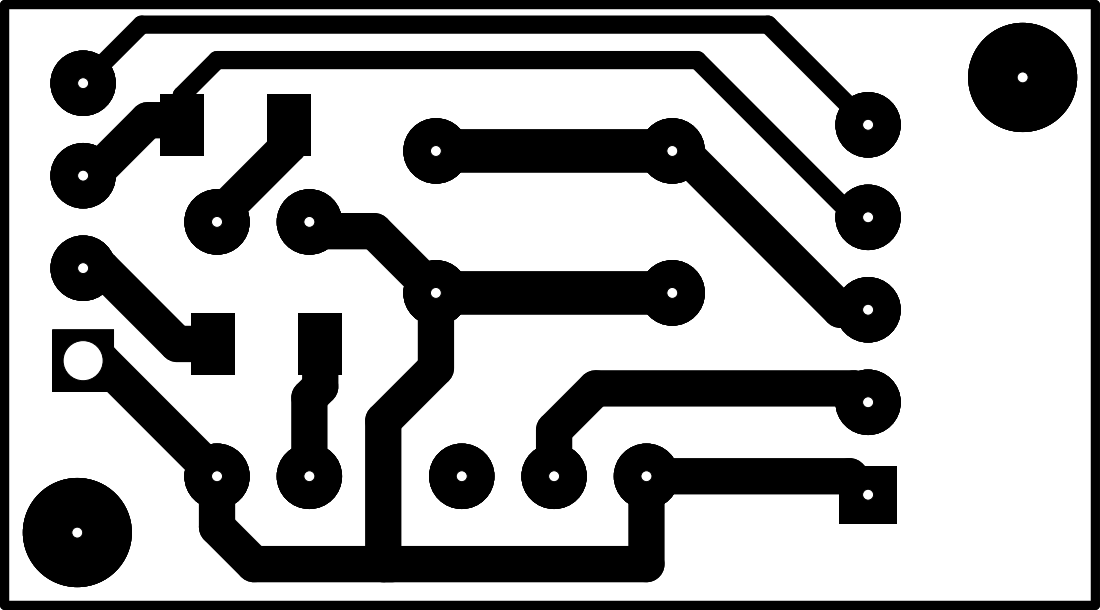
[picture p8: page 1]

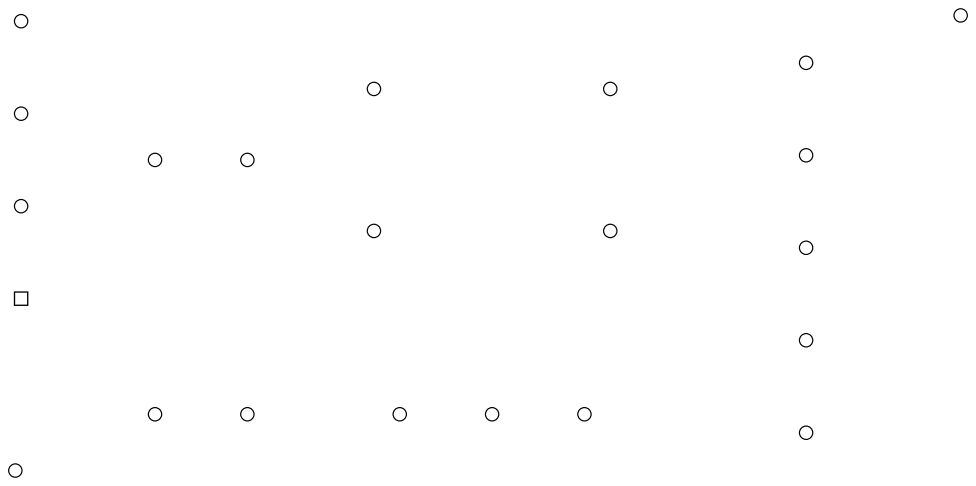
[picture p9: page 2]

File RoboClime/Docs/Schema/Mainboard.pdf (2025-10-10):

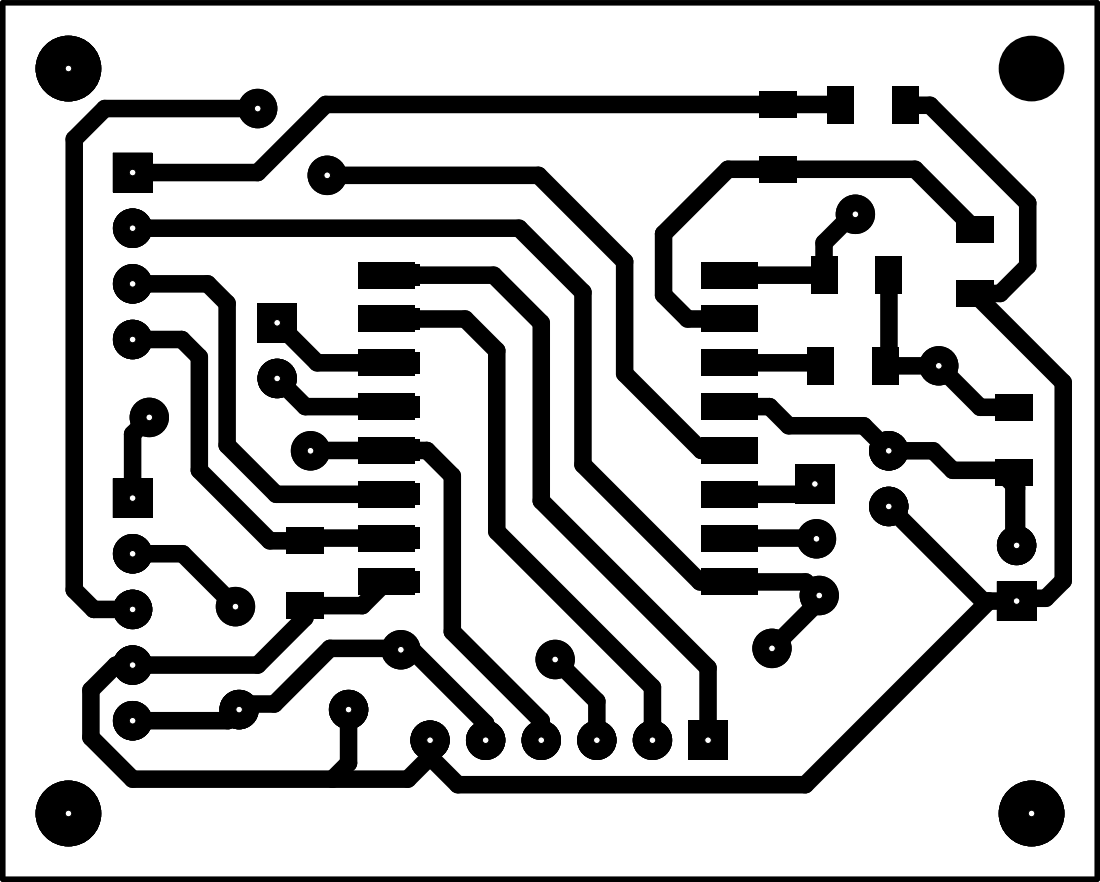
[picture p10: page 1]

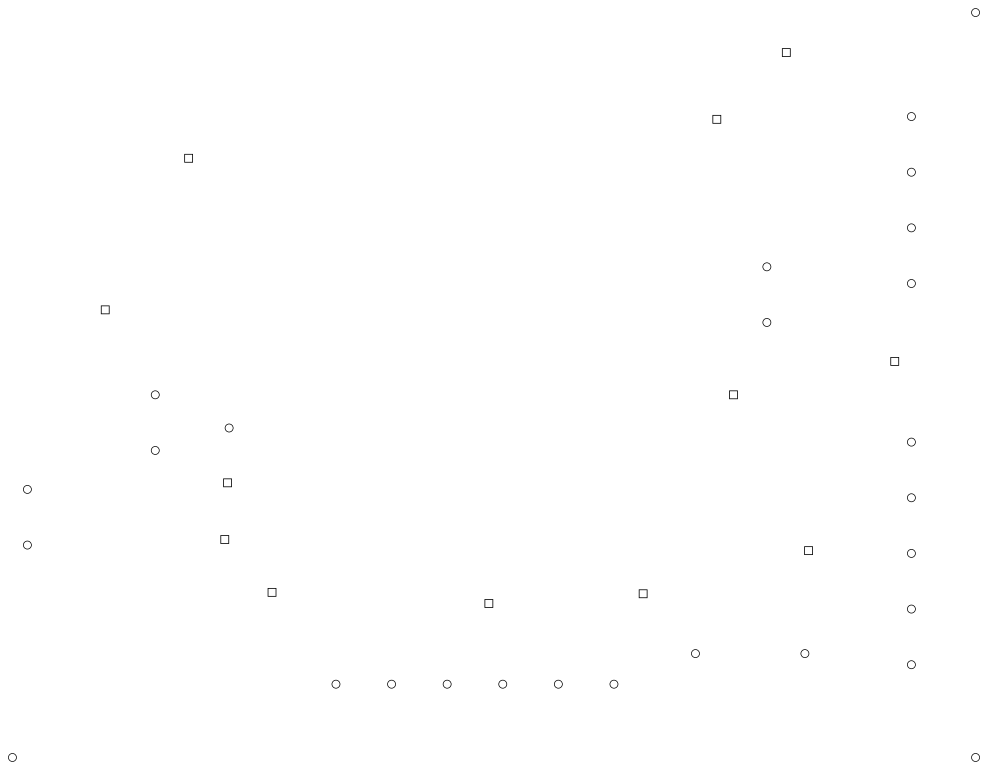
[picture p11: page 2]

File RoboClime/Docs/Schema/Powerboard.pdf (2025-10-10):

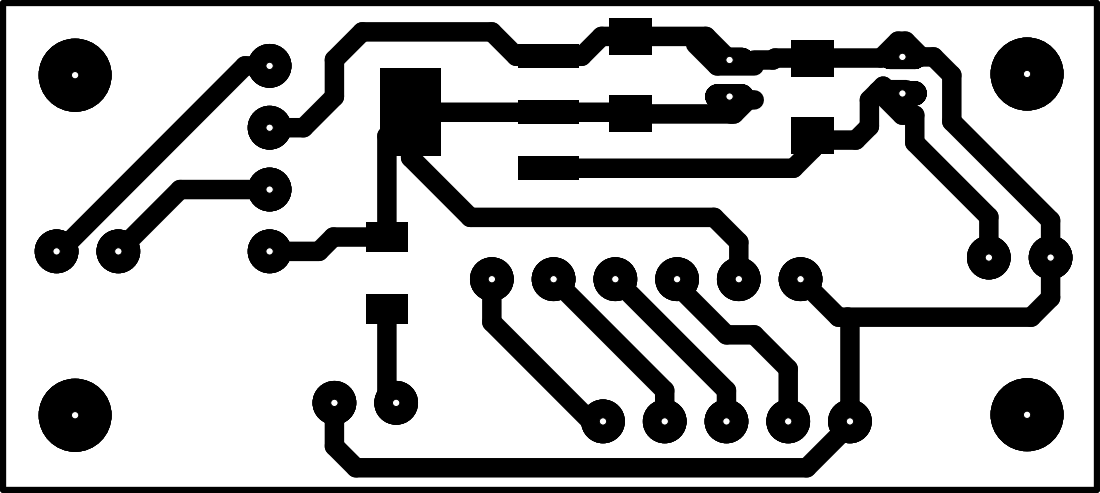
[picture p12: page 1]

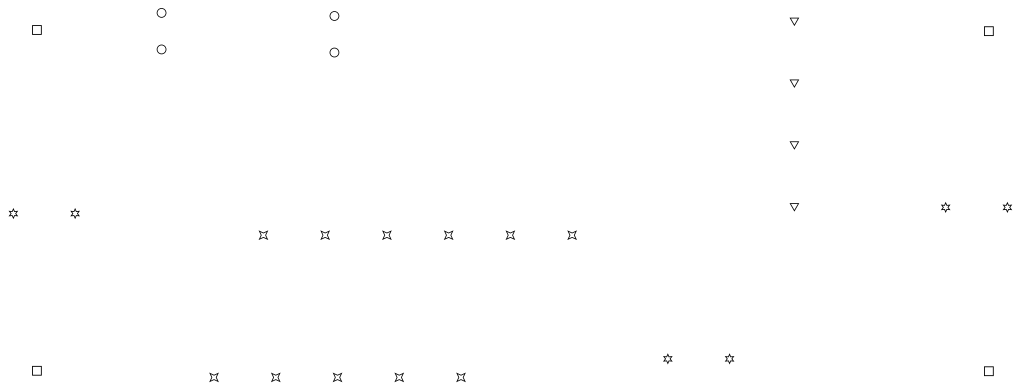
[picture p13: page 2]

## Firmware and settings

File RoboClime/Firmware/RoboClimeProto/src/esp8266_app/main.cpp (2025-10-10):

#include "constants.h"
#include "TypeDef.h"
#include "IDisplay.h"
#include "DisplayTFT_1_28.h"
#include "ISensorBmp280.h"
#include "ISensorAht21.h"
#include "SensorAht21.h"
#include "common.h"
#include "IMainController.h"
#include "ILog.h"
#include "EventLib.h"
#include "ButtonLib.h"


DisplayTFT_1_28 gDisplayTFT_1_28;
DisplayTFT_1_28* pDisplay = &gDisplayTFT_1_28;
//IDisplay* gDisplay = &gDisplayTFT_1_28;


SensorAht21 gSensorAHT21;
ISensorAht21* pSensorAHT21 = &gSensorAHT21;

DataAht21 gDataAht21;
float maxTemp = 0;
float minTemp = 0;  

unsigned long lastResetTimer = 0;
unsigned long lastReadTimer = 0;

DisplayData _displayData;

EventLib::EventDispatcher dispatcher;

ButtonLib::Button button(1, 16, dispatcher);  // ID=1, GPIO16

class MainController : public EventLib::IEventHandler {
  private:
    unsigned short _SheetNumber = 0;  
  public:
    void handleEvent(const EventLib::Event& event) override {
      // Обработка событий от кнопки
      Serial.println("Button event received");
      _SheetNumber = (_SheetNumber==1?0:1);
    }

    unsigned short GetSheetNumber()
    {
      return _SheetNumber;
    }
};

MainController controller;

//////////////////////////

// Display tft 1.28
void renderDisplay()
{
  float elapsed = 100*(millis()-lastResetTimer)/(RESET_PERIOD); //todo: убрать первую 10ку
  
  _displayData.SheetNumber = controller.GetSheetNumber();
  _displayData.CurrentTemperature = gDataAht21.Temperature;
  _displayData.MaxTemperature = maxTemp;
  _displayData.MinTemperature = minTemp;
  _displayData.ElapsedDayPercent = elapsed;
  //pDisplay->Draw(gDataAht21.Temperature, maxTemp, minTemp, elapsed);
  pDisplay->Draw(&_displayData);
} 

// SensorManager
void updateExtremum()
{
  minTemp = gDataAht21.Temperature < minTemp ? gDataAht21.Temperature : minTemp;
  maxTemp = gDataAht21.Temperature > maxTemp ? gDataAht21.Temperature : maxTemp;
}

void resetExtremum()
{
  for (int i=LOG_LENGTH-1; i>0; --i)
  {
    _displayData.MaxLog[i] = _displayData.MaxLog[i-1];
    _displayData.MinLog[i] = _displayData.MinLog[i-1];
  }
  _displayData.MaxLog[0] = maxTemp;
  _displayData.MinLog[0] = minTemp;

  minTemp = gDataAht21.Temperature;
  maxTemp = gDataAht21.Temperature;  
}

// Timer
bool checkResetTimer()
{
  return  (millis() - lastResetTimer) > RESET_PERIOD;
}

void resetTimer()
{
  lastResetTimer = millis();
}
//////////////////////////

void setup() {
  Serial.begin(115200);
  pSensorAHT21->Setup();

  gDataAht21 = pSensorAHT21->Read();
  maxTemp = gDataAht21.Temperature;
  minTemp = gDataAht21.Temperature;
  //resetExtremum();

  resetTimer();
  
  dispatcher.subscribe(&controller);
  lastReadTimer = millis(); // todo: удалить
}

void loop() {

  button.update();
  delay(20);

  if (_displayData.SheetNumber != controller.GetSheetNumber())
  {
    renderDisplay();
  }

  if (checkResetTimer())
  {
    resetTimer();
    resetExtremum();
  }

  if (millis() - lastReadTimer > DISPLAY_UPDATE_PERIOD)
  {
    lastReadTimer = millis();

    gDataAht21 = pSensorAHT21->Read();
    Serial.print("Temperature: "); Serial.print(gDataAht21.Temperature); Serial.println(" degrees C");
    Serial.print("Humidity: "); Serial.print(gDataAht21.Hummidity); Serial.println("% rH");
    updateExtremum();

    renderDisplay();

  }

 
  //delay(DISPLAY_UPDATE_PERIOD);
}

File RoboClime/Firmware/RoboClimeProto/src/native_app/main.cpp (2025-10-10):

#include <httplib.h>
#include "TypeDef.h"
#include "FSManagerNative.h"
#include "common.h"
#include "IMainController.h"

int main() {
    httplib::Server svr;  // Создаём сервер

    // Обработчик для корневого пути "/"
    String content;

    FSManagerNative fsManager;
    if (fsManager.Exists("index.html"))
    {
        content = fsManager.ReadFile("index.html");
    }
    else
    {
        content = "Error 404"; 
    }

    svr.Get("/", [&content](const httplib::Request&, httplib::Response& res) {
        res.set_content(content.c_str(), "text/html");
    });

    // Запуск сервера на порту 8080
    std::cout << "Server started at http://localhost:8080\n";
    svr.listen("localhost", 8080);

    return 0;
}

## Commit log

2025-10-10 JRH-002 Актуализировать проект
2025-10-27 JRHH-002-04 Аудит компонентов коммутации переменной нагрузки
